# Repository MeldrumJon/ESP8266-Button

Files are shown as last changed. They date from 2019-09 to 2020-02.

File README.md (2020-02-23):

# ESP8266-Button

Battery-powered WiFi button.

Can be used as an [IFTTT](https://ifttt.com/) trigger through 
[Webhooks](https://ifttt.com/maker_webhooks) or to 
control LIFX smart lights through the 
[LIFX HTTP API](https://api.developer.lifx.com/) or 
[LIFX LAN Protocol](https://lan.developer.lifx.com/).

Button with Enclosure

## Parts

- ESP8266-01 module
- Low quiescent current LDO 3.3V voltage regulator ([MCP1826S-3302E/AB](https://www.mouser.com/ProductDetail/579-MCP1826S-3302EAB))
- 4.7uF electrolytic capacitor
- 1uF electrolytic capacitor
- Momentary pushbutton switch
- SPDT mini slide switch, 3-pin, 2.54mm pin spacing
- 2x 1k resistors
- Battery holder for 3xAA or 3xAAA batteries
- Breakaway headers (optional, for ESP8266-01 module)
- 2-pin JST connector cables (optional, useful for buttons or batteries)
- Project Box 100x60x25 mm; inside dimensions: 96x56x23 mm

## Tools

- USB to TTL Serial **3.3V** adapter

## PCB

KiCAD files are in [the `hardware` Folder](./hardware).

ESP8266 LIFX Switch Schematic

## Assembled Box

ESP8266-Button Assembled

## Programming

### Setup

1. [Install the ESP8266 Arduino Core](https://github.com/esp8266/Arduino#installing-with-boards-manager)
2. Open one of the projects in [src/](./src/) in Arduino IDE.
3. In Arduino IDE,
	- Set `Tools->Board` to "Generic ESP8266 Module".
	- Set `Tools->Port` to your USB TTL Serial Adapter.
4. Connect the serial adapter's TX signal to RX on the ESP8266, RX to TX and 
GND to GND.
5. Update the `WIFI_SSID`, `WIFI_PASSWORD` and any other variables/macros marked
"TODO" to match your WiFi settings.

### Uploading

1. Set the slide switch to hold GPIO0 low.
2. Upload the sketch.
3. Whenever esptool.py tries to connect, press the pushbutton (to momentarily
hold RST low).
4. Wait for esptool to finish programming the ESP8266.
5. Move the slide switch back to hold GPIO0 high.

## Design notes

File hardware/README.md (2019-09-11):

## KiCAD Libraries

3rd-party KiCAD libraries (in `lib` folder) obtained from:

- [kicad-ESP8266](https://github.com/jdunmire/kicad-ESP8266)

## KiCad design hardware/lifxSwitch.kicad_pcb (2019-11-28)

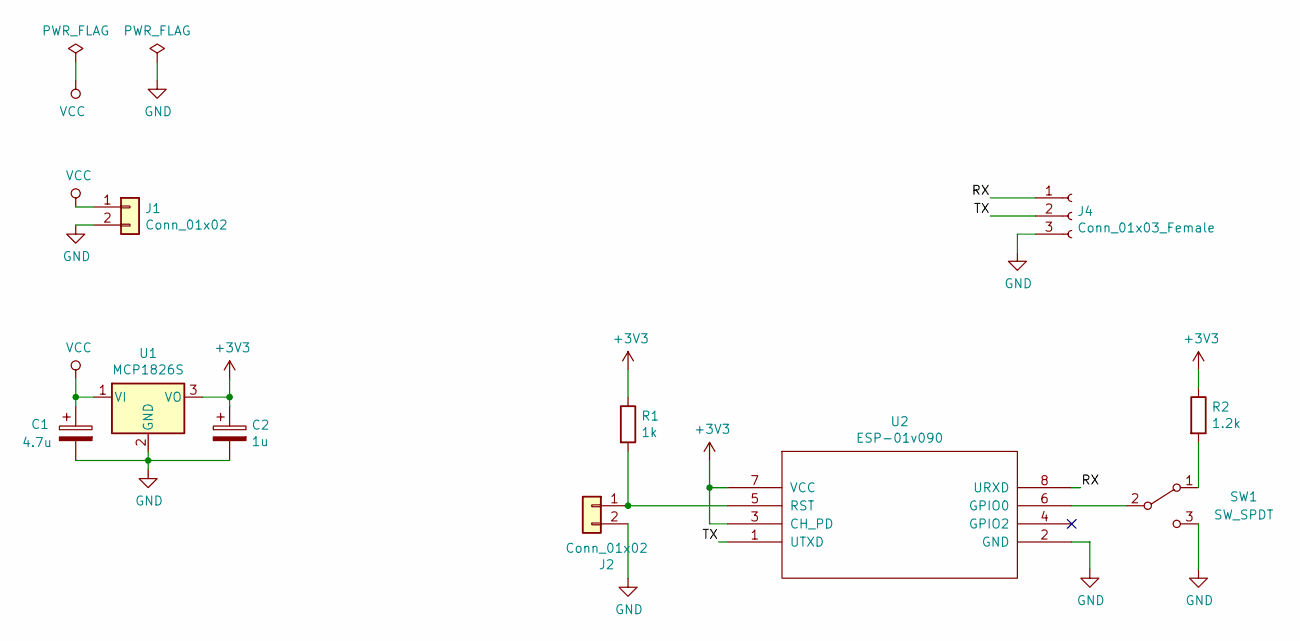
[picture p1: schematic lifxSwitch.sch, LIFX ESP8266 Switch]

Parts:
C1: 4.7u; CP_Radial_D5.0mm_P2.00mm
C2: 1u; CP_Radial_D5.0mm_P2.00mm
J1: Conn_01x02; SolderWirePad_1x02_P3.81mm_Drill1mm
J2: Conn_01x02; SolderWirePad_1x02_P3.81mm_Drill0.8mm
J4: Conn_01x03_Female; PinSocket_1x03_P2.54mm_Vertical
R1: 1k; R_Axial_DIN0207_L6.3mm_D2.5mm_P2.54mm_Vertical
R2: 1.2k; R_Axial_DIN0207_L6.3mm_D2.5mm_P2.54mm_Vertical
SW1: SW_SPDT; SPDT_THT_Slide_SW
U1: MCP1826S; TO-220-3_Horizontal_TabUp
U2: ESP-01v090; ESP-01

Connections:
+3V3: C2.1, R1.1, R2.1, U1.3 (VO), U2.3 (CH_PD), U2.7 (VCC)
/RX: J4.1, U2.8 (URXD)
/TX: J4.2, U2.1 (UTXD)
GND: C1.2, C2.2, J1.2, J2.2, J4.3, SW1.3 (C), U1.2 (GND), U2.2 (GND)
unnamed: J2.1, R1.2, U2.5 (RST)
unnamed: R2.2, SW1.1 (A)
unnamed: SW1.2 (B), U2.6 (GPIO0)
VCC: C1.1, J1.1, U1.1 (VI)

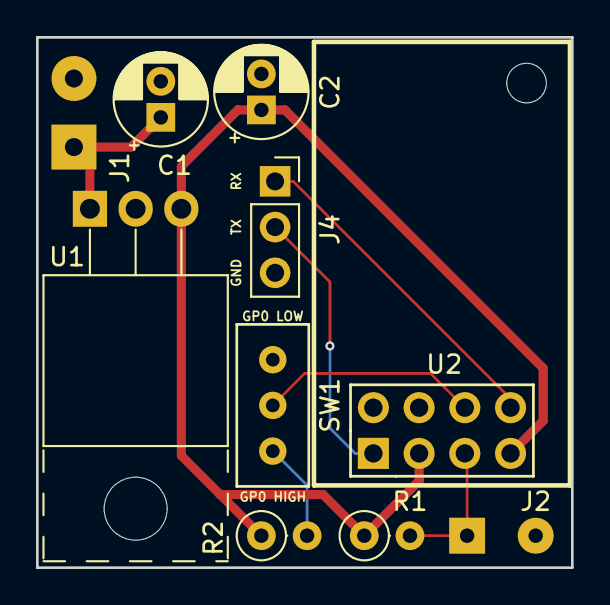
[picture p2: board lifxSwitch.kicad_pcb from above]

Board: 2 copper layers, 29.7 x 29.5 mm, 10 parts (0 on the bottom side), 8 nets.

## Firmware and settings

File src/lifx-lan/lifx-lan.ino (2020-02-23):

// Based on https://github.com/aijayadams/esp8266-lifx

#include <Arduino.h>
#include <ESP8266WiFi.h>
#include <WiFiUdp.h>

/*
 * Addresses and Settings
 */

// WiFi Settings
// TODO: Replace with your WiFi name and password
const char* const WIFI_SSID = "XXXXX";
const char* const WIFI_PASSWORD = "XXXXXXXX";

// Static IP address (for speed: using DHCP takes awhile)
// TODO: Set IP, GATEWAY, SUBNET, DNS to match router settings
// TODO: Assign a static IP to this device on your router
IPAddress IP(192, 168, 1, 71);
IPAddress GATEWAY(192, 168, 1, 1);
IPAddress SUBNET(255, 255, 255, 0);
IPAddress DNS(192, 168, 1, 1);
IPAddress BCAST(192, 168, 1, 255);

// LIFX MAC Address
// TODO: Replace with your LIFX bulb's MAC address
#define LIFX_TARGET {0x11, 0x22, 0x33, 0x44, 0x55, 0x66, 0x00, 0x00}

/*
 * UDP Setup
 */

#define LIFX_UDP_PORT 56700
#define BUFFER_LEN 128
char packetBuffer[BUFFER_LEN];
WiFiUDP UDP;

/*
 * LIFX Packets
 */

#define LIFX_HEADER_TARGET_LEN 8
#define LIFX_HEADER_RESERVED_LEN 6

#pragma pack(push, 1)
typedef struct {
    /* frame */
    uint16_t size; // Size of entire message in bytes including this field
    uint16_t protocol : 12; // Protocol number: must be 1024 (decimal)
    uint8_t addressable : 1; // Message includes a target address: must be one (1)
    uint8_t tagged : 1; // Determines usage of the Frame Address target field
    uint8_t origin : 2; // Message origin indicator: must be zero (0)
    uint32_t source; // Source identifier: unique value set by the client, used by responses
    /* frame address */
    uint8_t target[LIFX_HEADER_TARGET_LEN]; // 6 byte device address (MAC address) or zero (0) means all devices
    uint8_t reserved[LIFX_HEADER_RESERVED_LEN]; // Must all be zero (0)
    uint8_t res_required : 1; // Response message required
    uint8_t ack_required : 1; // Acknowledgement message required
    uint8_t : 6; // Reserved
    uint8_t sequence; // Wrap around message sequence number
    /* protocol header */
    uint64_t : 64; // Reserved
    uint16_t type; // Message type determines the payload being used
    uint16_t : 16; // Reserved
    /* variable length payload follows */
} lx_protocol_header_t;
#pragma pack(pop)

// Messages
#pragma pack(push, 1)
typedef struct {
    uint8_t service;
    uint32_t port;
} lx_msg_stateService_t;
#pragma pack(pop)

#pragma pack(push, 1)
typedef struct {
    uint16_t level;
    uint32_t duration;
} lx_msg_setPower_t;
#pragma pack(pop)

#pragma pack(push, 1)
typedef struct {
    uint16_t level;
} lx_msg_statePower_t;
#pragma pack(pop)

static void print_header(lx_protocol_header_t* head)
{
    Serial.println("HEADER");
    Serial.printf("Size: %d\n", head->size);
    Serial.printf("Protocol: %d\n", head->protocol);
    Serial.printf("Addressable: %d\n", head->addressable);
    Serial.printf("Tagged: %d\n", head->tagged);
    Serial.printf("Origin: %d\n", head->origin);
    Serial.printf("Source: %d\n", head->source);
    Serial.printf("Target: ");
    for (int i = 0; i < LIFX_HEADER_TARGET_LEN; ++i) {
        Serial.printf("%02X ", head->target[i]);
    }
    Serial.println();
    Serial.printf("Reserved: ");
    for (int i = 0; i < LIFX_HEADER_RESERVED_LEN; ++i) {
        Serial.printf("%02X ", head->reserved[i]);
    }
    Serial.println();
    Serial.printf("Response Required: %d\n", head->res_required);
    Serial.printf("Acknowledgement Required: %d\n", head->ack_required);
    Serial.printf("Sequence: %d\n", head->sequence);
    Serial.printf("Type: %d\n", head->type);
    Serial.println();
}

static void print_msgSetPower(lx_msg_setPower_t* msg)
{
    Serial.println("MESSAGE: SetPower");
    Serial.printf("Level: %d\n", msg->level);
    Serial.printf("Duration: %d\n", msg->duration);
    Serial.println();
}

static void print_msgStateService(lx_msg_stateService_t* msg)
{
    Serial.println("MESSAGE: StateService");
    Serial.printf("Service: %d\n", msg->service);
    Serial.printf("Port: %d\n", msg->port);
    Serial.println();
}

static void print_msgStatePower(lx_msg_statePower_t* msg)
{
    Serial.println("MESSAGE: StatePower");
    Serial.printf("Level: %d\n", msg->level);
    Serial.println();
}

/*
 * Defined LIFX Messages
 */

#define LIFX_SOURCE 3549

#define LIFX_TYPE_DISCOVERY 2
#define LIFX_TYPE_STATESERVICE 3
#define LIFX_TYPE_GETPOWER 20
#define LIFX_TYPE_SETPOWER 21
#define LIFX_TYPE_STATEPOWER 22
#define LIFX_TYPE_ACKNOWLEDGEMENT 45

static lx_protocol_header_t discovery_header = {
    sizeof(lx_protocol_header_t), // Size
    1024, // Protocol
    1, // Addressable
    1, // Tagged
    0, // Origin
    LIFX_SOURCE, // Source
    { 0x00, 0x00, 0x00, 0x00, 0x00, 0x00, 0x00, 0x00 }, // Target
    { 0x00, 0x00, 0x00, 0x00, 0x00, 0x00 }, // Reserved
    0, // Response Required
    0, // Acknowledge Requried
    0, // Sequence
    LIFX_TYPE_DISCOVERY // Type (Discovery)
};

static lx_protocol_header_t getPower_header = {
    sizeof(lx_protocol_header_t), // Size
    1024, // Protocol
    1, // Addressable
    0, // Tagged
    0, // Origin
    LIFX_SOURCE, // Source
    LIFX_TARGET, // Target
    { 0x00, 0x00, 0x00, 0x00, 0x00, 0x00 }, // Reserved
    1, // Response Requested
    0, // Acknowledge Requested
    0, // Sequence
    LIFX_TYPE_GETPOWER // Type (GetPower)
};

static lx_protocol_header_t setPower_header = {
    sizeof(lx_protocol_header_t) + sizeof(lx_msg_setPower_t),
    1024, // Protocol
    1, // Addressable
    0, // Tagged
    0, // Origin
    LIFX_SOURCE, // Source
    LIFX_TARGET, // Target
    { 0x00, 0x00, 0x00, 0x00, 0x00, 0x00 }, // Reserved
    0, // Response Requested
    1, // Acknowledge Requested
    0, // Sequence
    LIFX_TYPE_SETPOWER // Type (SetPower)
};

static lx_msg_setPower_t setPower_msg = {
    65535 // Level
};

/*
 * LIFX Functions
 */

// #define LIFX_DEBUG

int lifx_discover()
{
    int found = 0;

    UDP.beginPacket(BCAST, LIFX_UDP_PORT);
    UDP.write((char*)&discovery_header, sizeof(lx_protocol_header_t));
    UDP.endPacket();

    unsigned long started = millis();
    while (millis() - started < 250) { // Only search for 250ms
        int packetLen = UDP.parsePacket();
        if (packetLen && packetLen < BUFFER_LEN) {
            int read = UDP.read(packetBuffer, packetLen);
#ifdef LIFX_DEBUG
            Serial.printf("PacketLen: %d, read: %d\r\n", packetLen, read);
#endif
            lx_protocol_header_t* header = (lx_protocol_header_t*)packetBuffer;
            lx_msg_stateService_t* payload = (lx_msg_stateService_t*)(packetBuffer + sizeof(lx_protocol_header_t));
#ifdef LIFX_DEBUG
            print_header(header);
            print_msgStateService(payload);
#endif
            if (header->type == LIFX_TYPE_STATESERVICE) {
                ++found;
            } else {
#ifdef LIFX_DEBUG
                Serial.print("Unexpected Packet type: ");
                Serial.println(((lx_protocol_header_t*)packetBuffer)->type);
#endif
            }
        }
    }

    return found;
}

uint16_t lifx_getPower()
{
    uint16_t power = 0;

    // Try a few times
    for (int i = 0; i < 8; ++i) { // 2 seconds for response
        UDP.beginPacket(BCAST, LIFX_UDP_PORT);
        UDP.write((char*)&getPower_header, sizeof(lx_protocol_header_t));
        UDP.endPacket();

        unsigned long started = millis();
        while (millis() - started < 250) { // This ones important, wait 750ms for a response.
            int packetLen = UDP.parsePacket();
            if (packetLen && packetLen < BUFFER_LEN) {
                int read = UDP.read(packetBuffer, packetLen);
#ifdef LIFX_DEBUG
                Serial.printf("PacketLen: %d, read: %d\r\n", packetLen, read);
#endif
                lx_protocol_header_t* header = (lx_protocol_header_t*)packetBuffer;
                lx_msg_statePower_t* payload = (lx_msg_statePower_t*)(packetBuffer + sizeof(lx_protocol_header_t));
#ifdef LIFX_DEBUG
                print_header(header);
                print_msgStatePower(payload);
#endif
                if (header->type == LIFX_TYPE_STATEPOWER) {
                    power = payload->level;
                    return power;
                } else {
#ifdef LIFX_DEBUG
                    Serial.print("Unexpected Packet type: ");
                    Serial.println(((lx_protocol_header_t*)packetBuffer)->type);
#endif
                }
            }
        }
    }

    return power;
}

void lifx_setPower(uint16_t power)
{
    setPower_msg.level = power;

    // Try a few times
    for (int i = 0; i < 4; ++i) {
        UDP.beginPacket(BCAST, LIFX_UDP_PORT);
        UDP.write((char*)&setPower_header, sizeof(lx_protocol_header_t));
        UDP.write((char*)&setPower_msg, sizeof(lx_msg_setPower_t));
        UDP.endPacket();

        unsigned long started = millis();
        while (millis() - started < 250) { // This ones important, wait 1s for an acknowledgement.
            int packetLen = UDP.parsePacket();
            if (packetLen && packetLen < BUFFER_LEN) {
                int read = UDP.read(packetBuffer, packetLen);
#ifdef LIFX_DEBUG
                Serial.printf("PacketLen: %d, read: %d\r\n", packetLen, read);
#endif
                lx_protocol_header_t* header = (lx_protocol_header_t*)packetBuffer;
#ifdef LIFX_DEBUG
                print_header(header);
#endif
                if (header->type == LIFX_TYPE_ACKNOWLEDGEMENT) {
                    return;
                } else {
#ifdef LIFX_DEBUG
                    Serial.print("Unexpected Packet type: ");
                    Serial.println(((lx_protocol_header_t*)packetBuffer)->type);
#endif
                }
            }
        }
    }
    return;
}

/*
 * Wifi Setup
 */

void setup()
{
    unsigned long timeout;

    // Keep light on to show that the ESP8266 is not sleeping
    pinMode(2, OUTPUT);
    digitalWrite(2, LOW);

    Serial.begin(115200);
    //Serial.setDebugOutput(true);
    Serial.println();
    Serial.print("MAC: ");
    Serial.println(WiFi.macAddress());
    Serial.println("Connecting to WiFi...");

    // Connect to WiFi
    WiFi.mode(WIFI_STA);
    WiFi.config(IP, GATEWAY, SUBNET, DNS); // Comment out to use DHCP
    WiFi.begin(WIFI_SSID, WIFI_PASSWORD);
    timeout = millis() + 10000; // wait 10s
    while (WiFi.status() != WL_CONNECTED) {
        if (millis() > timeout) {
            break;
        }
        delay(1); // keep WDT happy
    }
    if (WiFi.status() != WL_CONNECTED) {
        Serial.println("Could not connect.");
        return; // Go to sleep
    }

    Serial.println("WiFi connected");
    Serial.print("IP address: ");
    Serial.println(WiFi.localIP());

    // Toggle light
    UDP.begin(LIFX_UDP_PORT);

    uint16_t pow = lifx_getPower();
    Serial.printf("Power level is %d.\r\n", pow);
    if (pow > 32768) {
        pow = 0;
    } else {
        pow = 65535;
    }
    Serial.printf("Setting power to %d.\r\n", pow);
    lifx_setPower(pow);
    return;
}

void loop()
{
    ESP.deepSleep(0); // Sleep forever
}

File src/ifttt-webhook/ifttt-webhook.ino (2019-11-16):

// Based on https://github.com/RuiSantosdotme/Random-Nerd-Tutorials/blob/master/Projects/ESP8266_WiFi_Button.ino

#include <Arduino.h>
#include <ESP8266WiFi.h>

/*
 * Addresses and Settings
 */

// WiFi Settings
const char* const WIFI_SSID = "wifi_name"; // TODO: replace with your SSID
const char* const WIFI_PASSWORD = "password"; // TODO: replace with your password

// Static IP address (for speed: using DHCP takes awhile)
// TODO: Set IP, GATEWAY, SUBNET, DNS to match router settings
IPAddress IP(192, 168, 1, 71); // TODO: assign a static IP to this device on your router
IPAddress GATEWAY(192, 168, 1, 1);
IPAddress SUBNET(255, 255, 255, 0);
IPAddress DNS(192, 168, 1, 1);

// TODO: these should match the URL for your webhooks event. Update the trigger and API key.
const char* const SERVER = "maker.ifttt.com";
const char* const RESOURCE = "/trigger/btn_press/with/key/mYALpHanuMEriCkEY";

/*
 * HTTP Setup
 */

#define PORT 80
WiFiClient client;

/*
 * Wifi Setup
 */

void setup()
{
    unsigned long timeout;
  
    // Keep light on to show that the ESP8266 is not sleeping
    pinMode(2, OUTPUT);
    digitalWrite(2, LOW);

    Serial.begin(115200);
    //Serial.setDebugOutput(true);
    Serial.println();
    Serial.print("MAC: ");
    Serial.println(WiFi.macAddress());
    Serial.println("Connecting to WiFi...");

    // Connect to WiFi
    WiFi.config(IP, GATEWAY, SUBNET, DNS); // Comment out to use DHCP
    WiFi.begin(WIFI_SSID, WIFI_PASSWORD);
    timeout = millis() + 10000; // wait 10s
    while (WiFi.status() != WL_CONNECTED) {
        if (millis() > timeout) {
            break;
        }
        delay(1); // keep WDT happy
    }
    if (WiFi.status() != WL_CONNECTED) {
        Serial.println("Could not connect.");
        return; // Go to sleep
    }

    Serial.println("WiFi connected");
    Serial.print("IP address: ");
    Serial.println(WiFi.localIP());

    // Connect to IFTTT web service
    Serial.print("Connecting to ");
    Serial.println(SERVER);
    if (!client.connect(SERVER, PORT)) {
        Serial.println("Could not connect!");
        return; // Go to sleep
    }
    Serial.print("Requesting resource ");
    Serial.println(RESOURCE);
    client.print(String("GET ") + RESOURCE + 
                  " HTTP/1.1\r\n" +
                  "Host: " + SERVER + "\r\n" + 
                  "Connection: close\r\n\r\n");

    // Wait for Response
    timeout = millis() + 5000; // wait 5s
    while (!client.available()) {
        if (millis() > timeout) {
            return; // Go to sleep
        }
        delay(1); // keep WDT happy
    }
    // Print response
    Serial.println("RESPONSE");
    while (client.available()) {
        char c = client.read();
        Serial.write(c);
    }

    return; // Go to sleep.
}

void loop()
{
    ESP.deepSleep(0); // Sleep forever
}

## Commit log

2019-07-03 Ability to read power from LIFX bulb
2019-07-27 Switch working
2019-09-11 Working PCB v0.1
    [lifxSwitch.kicad_pcb, lifxSwitch.sch]
2019-09-11 Include 3rd Party Libraries
    [lifxSwitch.kicad_pcb, lifxSwitch.sch]
2019-10-22 Separate code, PCB into own folders
2019-11-28 Add GND header, Label RX, TX, GPIO0 switch
    [lifxSwitch.kicad_pcb]
2019-11-28 Small silkscreen update
    [lifxSwitch.kicad_pcb]
